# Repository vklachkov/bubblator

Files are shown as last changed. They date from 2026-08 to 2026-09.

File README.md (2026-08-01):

# Bubblator

> [!WARNING]
> This project is unfinished. Nothing is known to work yet. Do not use this board with real bubble-memory modules. It may damage rare hardware. Please wait for tested hardware, firmware, and clear operating instructions.

Bubblator is an experimental board for reading, writing, and attempting to restore Intel 7110 bubble-memory modules.

It follows the Intel Bubble Memory System design and uses the following main parts:

- Intel 7110 / 7110A(Z) One Megabit Bubble Memory Unit
- Intel 7220-1 Bubble Memory Controller
- Intel 7230 Current Pulse Generator
- Intel 7242 Formatter/Sense Amplifier
- Intel 7250 Coil Predriver
- 2x Intel 7254 driver transistors
- Arduino Nano

Firmware serial commands are described in [firmware/COMMANDS.md](firmware/COMMANDS.md).

## Documentation Used

The following Intel documents were used during development:

- [Megabits to Megabytes: Bubble Memory System Design and Board Layout (AP-187, 1984)](https://archive.org/details/bitsavers_intelbubbl87MegabitsToMegabytesBubbleMemorySystemD_3867950) - system design, board layout, and implementation guidance.
- [Intel Bubble Memory Design Handbook](https://archive.org/details/IntelBubbleMemoryDesignHandbook) - bubble-memory principles and design reference.
- [Intel BPK72 Bubble Storage Prototype Kit](https://web.archive.org/web/20190419090939/https://www.wolfgangrobel.de/museum/files_bubble5/intel%20BPK72%20Prototype%20kit%20users%20manual.pdf) - reference prototype system and kit documentation.
- [Intel 7220 Controller for 1Mbit BPK 70A Bubble Memory Subsystem](https://web.archive.org/web/20250912182130/https://wolfgangrobel.de/museum/files_bubble5/intel%207220%20bubble%20memory%20controller.pdf) - datasheet for the Intel 7220 bubble-memory controller.

Further project background:
- [ArduBubble / ReBubbling on the Unix Haters Wiki](https://wiki.unix-haters.org/doku.php?id=grid:rebubbling)

## Authors

- **sabur** - original firmware code.
- **grm** - initial hardware design.
- **BOOtak** - created the second PCB revision and assembled the prototype.
- **vklachkov** - continued the work of others.

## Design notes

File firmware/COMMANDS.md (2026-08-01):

# Firmware Serial Commands

> [!WARNING]
> The firmware and hardware are unfinished. Do not use write, reset, purge, or other commands with a real bubble-memory module. They may change data or damage rare hardware.

> [!NOTE]
> An LLM created this document by reading `firmware.ino`. Treat it with great caution. It has not been verified.

The firmware uses the Arduino Nano USB serial port at **115200 baud**. Send one command per line. Both `LF` and `CR` line endings are accepted. Command letters are case-insensitive.

The command line is limited to 63 characters. A longer line is discarded.

## Basic Commands

| Command | Description |
| --- | --- |
| `i0` | Release reset and load normal parameters: two formatter/sense amplifier (FSA) channels and one page per transfer. |
| `i1` | Release reset and load diagnostic parameters: one FSA channel and one page per transfer. |
| `i2` | Release reset and load Write Bootloop parameters. This enables writing to the bootloop. |
| `r` | Assert controller reset when it is not busy. Run `i0`, `i1`, or `i2` afterwards to release reset. |
| `rf` | Force reset even when the controller reports busy. This may cause data loss. Run an `i` command afterwards to release reset. |
| `s` | Read and print the controller status register. |
| `fr` | Read the controller FIFO and print its contents. |
| `fw <hex bytes>` | Write hexadecimal bytes to the controller FIFO. At most 43 bytes are written. |

For `fw`, values may be separated by spaces, commas, or colons. The `0x` prefix is optional. Each value may have one or two hexadecimal digits; one digit is stored as `0x0N`. For example:

```text
fw FF 00 A5 7E
fw 0xFF,0x00,0xA5,0x7E
```

## Controller Commands

Use `c` followed by a command code. For example, `c1` sends the controller Initialize command. These commands directly access the Intel 7220 controller.

| Command | Intel 7220 operation | Notes |
| --- | --- | --- |
| `c0` | Write Bootloop Register Masked | Direct controller command. |
| `c1` | Initialize | Direct controller command. |
| `c2` | Read Bubble Data | Direct controller command. |
| `c3` | Write Bubble Data | Direct controller command. |
| `c4` | Read Seek | Direct controller command. |
| `c5` | Read Bootloop Register | Direct controller command. |
| `c6` | Write Bootloop Register | Not implemented: the firmware does not send this command. |
| `c7` | Write Bootloop | Not implemented: the firmware does not send this command. |
| `c8` | Read FSA Status | Direct controller command. |
| `c9` | Abort | Abort the current operation. After it completes, run Initialize or MBM Purge; MBM Purge may be destructive. |
| `ca` | Write Seek | Direct controller command. |
| `cb` | Read Bootloop | Direct controller command. |
| `cc` | Read Corrected Data | Direct controller command. |
| `cd` | Reset FIFO | Direct controller command. |
| `ce` | MBM Purge | Direct controller command. This is potentially destructive. |
| `cf` | Software Reset | Direct controller command. |
| `cx` | Fill FIFO with 34 ones | Not implemented. |
| `cz` | Fill FIFO with 40 ones | Not implemented. |

After each `c` command, the firmware polls for completion or failure for up to about two seconds. It prints `Operation Timed Out!` if neither status appears. This wait also runs for the unimplemented commands. Some direct commands require correctly configured registers and FIFO contents; the firmware does not validate that setup.

## Page Read and Write

Page commands are sent as controller commands with `r` or `w` as the code:

```text
cr <first page> [last page]
cw <first page> [last page]
```

Examples:

```text
cr 0
cr 10 15
cw 42
```

Pages are decimal numbers from `0` to `2047`. A comma or colon may also separate the two page numbers. An omitted or invalid first page defaults to `0`. An omitted or invalid last page defaults to the selected first page.

- `cr` reads one page or an inclusive page range. Each page contains 68 bytes: 64 data bytes and 4 error-correction bytes. The result is printed in hexadecimal and printable ASCII.
- `cw` writes one page or an inclusive page range. **The current firmware always writes `FF` to all 68 bytes of every selected page.** It makes at most five write attempts per page. The current code may print `Abort...` after the fifth attempt even when that final attempt succeeds.

Both commands can wait forever for `FIFOReady` if the controller is unavailable or incorrectly configured. There is no timeout for this wait.

Do not run `cw` on a real module.

## Status Output

The `s` command can print these flags:

- `Busy` - controller operation is in progress.
- `OpComplete` - the operation completed.
- `OpFail` - the operation failed.
- `TimingError`, `CorrectableError`, `UncorrectableError`, and `ParityError` - controller error conditions.
- `FIFOReady` - data is available in the FIFO.

## Unavailable Commands

The parser also accepts `a` and `u`, but their handlers are disabled in the current firmware. They require one parameter character (for example, `ax` or `ux`) and then have no effect. `a` or `u` alone reports a missing parameter.

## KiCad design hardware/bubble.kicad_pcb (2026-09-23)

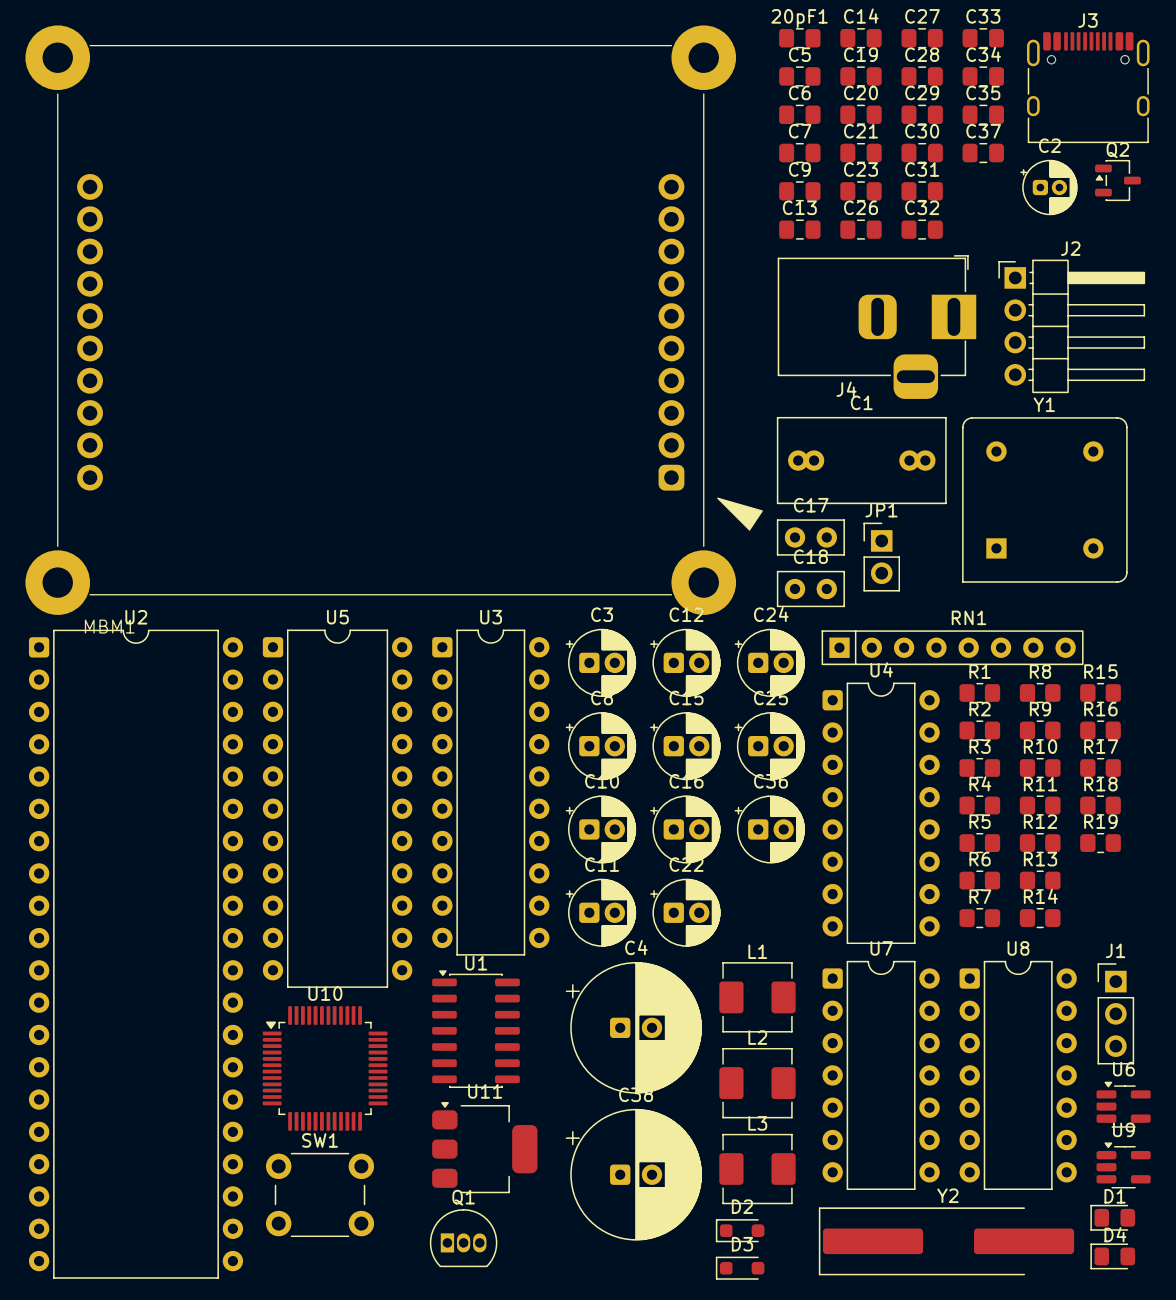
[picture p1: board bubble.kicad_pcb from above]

Board: 4 copper layers, 88 parts (0 on the bottom side), 103 nets, no tracks yet.

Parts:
20pF1: C; C_0805_2012Metric_Pad1.18x1.45mm_HandSolder
C1: 0.33 uF; C_Rect_L13.0mm_W6.5mm_P7.50mm_P10.00mm
C2: 22uF; CP_Radial_D4.0mm_P1.50mm
C3, C8, C10, C11, C36: 47uF; CP_Radial_D5.0mm_P2.00mm
C4, C38: 150uF; CP_Radial_D10.0mm_P2.50mm
C5, C6, C7, C9, C13, C14, C19, C20, C21, C31, C32, C33, C35, C37: 0.1uF; C_0805_2012Metric_Pad1.18x1.45mm_HandSolder
C12, C15, C22, C24, C25: 22uF; CP_Radial_D5.0mm_P2.00mm
C16: 22uF 25V; CP_Radial_D5.0mm_P2.00mm
C17, C18: 120 pF 100V 5%; C_Disc_D5.0mm_W2.5mm_P2.50mm
C23: 2.2 uF; C_0805_2012Metric_Pad1.18x1.45mm_HandSolder
C26, C27: 0.01 uF; C_0805_2012Metric_Pad1.18x1.45mm_HandSolder
C28: 10 uF; C_0805_2012Metric_Pad1.18x1.45mm_HandSolder
C29: 20pF; C_0805_2012Metric_Pad1.18x1.45mm_HandSolder
C30, C34: 22uF; C_0805_2012Metric_Pad1.18x1.45mm_HandSolder
D1: POWER FAILED LED; LED_0805_2012Metric_Pad1.15x1.40mm_HandSolder
D2, D3: D; D_SOD-323_HandSoldering
D4: LED; LED_0805_2012Metric_Pad1.15x1.40mm_HandSolder
J1: Conn_01x03_Pin; PinHeader_1x03_P2.54mm_Vertical
J2: Conn_01x04_Pin; PinHeader_1x04_P2.54mm_Horizontal
J3: USB-C; USB_C_Receptacle_HRO_TYPE-C-31-M-12
J4: 12V Power; BarrelJack_Horizontal
JP1: Only for reseed; PinHeader_1x02_P2.54mm_Vertical
L1, L2, L3: 0.22 uH; L_APV_APH0530
MBM1: i7110; MBM_socket
Q1: BS170; TO-92_Inline
Q2: DTC113Z; SOT-23-3
R1, R2, R13, R15, R16: 5.1k; R_0805_2012Metric_Pad1.20x1.40mm_HandSolder
R3: 3.48k; R_0805_2012Metric_Pad1.20x1.40mm_HandSolder
R4: 10; R_0805_2012Metric_Pad1.20x1.40mm_HandSolder
R5: 300; R_0805_2012Metric_Pad1.20x1.40mm_HandSolder
R6: 47; R_0805_2012Metric_Pad1.20x1.40mm_HandSolder
R7: 1k; R_0805_2012Metric_Pad1.20x1.40mm_HandSolder
R8: 3.9k; R_0805_2012Metric_Pad1.20x1.40mm_HandSolder
R9: 5.5k; R_0805_2012Metric_Pad1.20x1.40mm_HandSolder
R10: 33k; R_0805_2012Metric_Pad1.20x1.40mm_HandSolder
R11, R12: 5.1; R_0805_2012Metric_Pad1.20x1.40mm_HandSolder
R14: 300Ohm; R_0805_2012Metric_Pad1.20x1.40mm_HandSolder
R17, R18: 22; R_0805_2012Metric_Pad1.20x1.40mm_HandSolder
R19: 1.5k; R_0805_2012Metric_Pad1.20x1.40mm_HandSolder
RN1: 1k; R_Array_SIP8
SW1: Reset; SW_PUSH_6mm_H5mm
U1: 74LS74; SOIC-14_3.9x8.7mm_P1.27mm
U2: i7220; DIP-40_W15.24mm
U3: i7242; DIP-20_W7.62mm
U4: i7250; DIP-16_W7.62mm
U5: i7230; DIP-22_W10.16mm
U6: 74AHC1G00; SOT-23-5_HandSoldering
U7, U8: i7254; DIP-14_W7.62mm
U9: 74LVC1G07; SOT-23-5_HandSoldering
U10: STM32F103C8Tx; LQFP-48_7x7mm_P0.5mm
U11: AMS1117-3.3; SOT-223-3_TabPin2
Y1: 8.000 MHz; Oscillator_DIP-8
Y2: 8Mhz; Crystal_SMD_HC49-SD_HandSoldering

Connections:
+3.3V: C33.1, C34.1, J1.3, J2.4, R19.2, U10.9 (VDDA), U10.24 (VDD), U10.36 (VDD), U10.48 (VDD), U11.2 (VO)
+5V: C5.1, C8.1, C11.1, C13.1, C30.1, C32.1, C35.2, C36.2, D1.2 (A), J3.A4 (VBUS), J3.A9 (VBUS), J3.B4 (VBUS), J3.B9 (VBUS), L1.2, R1.1, R2.1, R7.1, R13.2, U1.1 (~R), U1.4 (~S), U1.14 (VCC), U2.40 (VCC), U3.20 (VCC), U6.5 (VCC), U9.5 (VCC), U11.3 (VI), Y1.1 (EN), Y1.8 (Vcc)
+12V: C9.1, C10.1, C12.1, C20.1, C21.1, C24.1, C25.1, C37.1, C38.1, J4.1, JP1.2 (B), L2.2, R4.2, R6.2, R11.2, U4.16 (VDD), U7.6 (S2), U7.13 (S4), U8.6 (S2), U8.13 (S4)
/MBM/7230 VCC: C4.1, C7.1, L3.1, U5.22 (VCC)
/MBM/7230 VDD: C2.1, C3.1, C6.1, L2.1, U5.1 (VDD)
/MBM/~7220 POWER.FAIL: C23.1, C26.1, D3.2 (A), Q2.3 (C), R8.2, U2.1 (~PWR.FAIL)
/MBM/~7220 RESET.OUT: R13.1, U2.2 (~RESET.OUT), U6.2, U9.2
A0: U2.10 (A0), U10.42 (PB6)
BOOT: J1.2, U10.44 (BOOT0)
CLK: U1.5 (Q), U2.3 (CLK), U3.18 (CLK), U10.3 (PC14)
D0: U2.11 (D0), U10.43 (PB7)
D1: U2.12 (D1), U10.45 (PB8)
D2: U2.13 (D2), U10.46 (PB9)
D3: U2.14 (D3), U10.21 (PB10)
D4: U2.15 (D4), U10.22 (PB11)
D5: U2.16 (D5), U10.25 (PB12)
D6: U2.17 (D6), U10.26 (PB13)
D7: U2.18 (D7), U10.27 (PB14)
D8: U2.19 (D8), U10.28 (PB15)
DRQ: U2.8 (DRQ), U10.29 (PA8)
GND: 20pF1.1, C1.2, C2.2, C3.2, C4.2, C5.2, C6.2, C7.2, C8.2, C9.2, C10.2, C11.2, C12.2, C13.2, C14.2, C15.2, C20.2, C21.2, C23.2, C24.2, C25.2, C26.2, C27.2, C28.2, C29.1, C30.2, C31.1, C32.2, C33.2, C34.2, C35.1, C36.1, C37.2, C38.2, J1.1, J2.1, J3.A1 (GND), J3.A12 (GND), J3.B1 (GND), J3.B12 (GND), J3.SH (SHIELD), J4.2, Q1.3 (S), Q2.2 (E), R10.2, R12.1, R14.1, R15.2, R16.1, SW1.2, U1.7 (GND), U2.20 (GND), U3.1 (~CS), U3.10 (GND), U4.8 (GND), U5.11 (GND), U5.12 (GND), U6.3 (GND), U7.2 (S1), U7.9 (S3), U8.2 (S1), U8.9 (S3), U9.3 (GND), U10.8 (VSSA), U10.23 (VSS), U10.35 (VSS), U10.47 (VSS), U11.1 (GND), Y1.4 (GND)
INT: U2.9 (INT), U10.39 (PB3)
NRST: C31.2, SW1.1, U10.7 (NRST)
unnamed: C1.1, L1.1, L3.2
unnamed: C16.2, MBM1.1 (PULSE.COM(+12V)), MBM1.6 (PULSE.COM(+12V))
unnamed: D1.1 (K), R5.2
unnamed: D2.1 (K), R8.1
unnamed: D3.1 (K), R9.1
unnamed: D4.1 (K), R14.2
unnamed: J3.A5 (CC1), R15.1
unnamed: J3.B5 (CC2), R16.2
unnamed: J3.A6 (D+), J3.B6 (D+), R18.1, R19.1
unnamed: J3.A7 (D-), J3.B7 (D-), R17.1
unnamed: C16.1, JP1.1 (A), R6.1
unnamed: MBM1.4 (BOOT.REP), U5.13 (BOOT.REP)
unnamed: MBM1.5 (BOOT.SWAP), U5.14 (BOOT.SWAP)
unnamed: C19.2, C22.2, MBM1.15 (DET.COM), R12.2
unnamed: MBM1.19 (DET.OUT.A+), RN1.5 (R4.2)
unnamed: MBM1.18 (DET.OUT.A-), RN1.6 (R3.2)
unnamed: MBM1.17 (DET.OUT.B+), RN1.7 (R2.2)
unnamed: MBM1.16 (DET.OUT.B-), RN1.8 (R1.2)
unnamed: C19.1, C22.1, MBM1.20 (DET.SUPPLY), R11.1
unnamed: MBM1.7 (GEN.A), U5.18 (GEN.A)
unnamed: MBM1.8 (GEN.B), U5.19 (GEN.B)
unnamed: MBM1.3 (REP.A), U5.15 (REP.A)
unnamed: MBM1.2 (REP.B), U5.16 (REP.B)
unnamed: MBM1.13 (SWAP.A), MBM1.14 (SWAP.B), U5.17 (SWAP)
unnamed: MBM1.10 (X+.COIL.IN), U7.7 (D2), U7.8 (D3)
unnamed: MBM1.9 (X-.COIL.IN), U7.1 (D1), U7.14 (D4)
unnamed: MBM1.12 (Y+.COIL.IN), U8.1 (D1), U8.14 (D4)
unnamed: MBM1.11 (Y-.COIL.IN), U8.7 (D2), U8.8 (D3)
unnamed: Q1.1 (D), R3.1
unnamed: Q2.1 (B), U6.4
unnamed: C18.2, RN1.1 (R1.1), U3.9 (DET.B-)
unnamed: C18.1, RN1.2 (R2.1), U3.8 (DET.B+)
unnamed: C17.2, RN1.3 (R3.1), U3.7 (DET.A-)
unnamed: C17.1, RN1.4 (R4.1), U3.6 (DET.A+)
unnamed: U1.3 (C), Y1.5 (OUT)
unnamed: U1.2 (D), U1.6 (~Q)
unnamed: U2.29 (C/~D), U3.3 (C/~D)
unnamed: U2.22 (DIO), U3.17 (DIO)
unnamed: U2.32 (~BOOT.EN), U5.10 (~BOOT.EN)
unnamed: U2.30 (~BOOT.SW.EN), U5.9 (~BOOT.SW.EN)
unnamed: U2.33 (~REP.EN), U5.8 (~REP.EN)
unnamed: U2.24 (~SHIFT.CLK), U3.15 (~SHIFT.CLK)
unnamed: U2.31 (~SWAP.EN), U5.6 (~SWAP.EN)
unnamed: U2.23 (~SYNC), U3.19 (~SELECT.IN)
unnamed: U2.35 (~TM.A), U5.2 (~TM.A)
unnamed: U2.34 (~TM.B), U5.3 (~TM.B)
unnamed: U2.39 (~X+), U4.3 (~X+.IN)
unnamed: U2.38 (~X-), U4.4 (~X-.IN)
unnamed: U2.37 (~Y+), U4.5 (~Y+.IN)
unnamed: U2.36 (~Y-), U4.6 (~Y-.IN)
unnamed: C14.1, C15.1, R4.1, U3.5 (VDD)
unnamed: U3.11 (~DATA.OUT.A), U5.5 (~GEN.EN.A)
unnamed: U3.12 (~DATA.OUT.B), U5.4 (~GEN.EN.B)
unnamed: U3.13 (~ENABLE.A), U4.1 (~CS), U5.7 (~CS)
unnamed: U4.14 (X+.OUT), U7.3 (G1)
unnamed: U4.12 (X-.OUT), U7.10 (G3)
unnamed: U4.10 (Y+.OUT), U8.10 (G3)
unnamed: U4.7 (Y-.OUT), U8.3 (G1)
unnamed: U4.15 (~X+.OUT), U7.5 (G2)
unnamed: U4.13 (~X-.OUT), U7.12 (G4)
unnamed: U4.11 (~Y+.OUT), U8.12 (G4)
unnamed: U4.9 (~Y-.OUT), U8.5 (G2)
unnamed: R3.2, U5.20 (REFR)
unnamed: C29.2, U10.5 (PD0), Y2.2
unnamed: 20pF1.2, U10.6 (PD1), Y2.1
STATUS_LED: D4.2 (A), U10.2 (PC13)
SWCLK: J2.2, U10.37 (PA14)
SWDIO: J2.3, U10.34 (PA13)
USB_D+: R18.2, U10.33 (PA12)
USB_D-: R17.2, U10.32 (PA11)
~BUS.RD: U2.25 (~BUS.RD), U10.31 (PA10)
~CS: U2.21 (~CS), U10.4 (PC15)
~DACK: U2.7 (~DACK), U10.30 (PA9)
~DET.ON: U2.28 (~DET.ON), U10.40 (PB4)
~ERR_FLAG: R1.2, U2.27 (~ERR.FLG), U3.4 (~ERR.FLG), U10.41 (PB5)
~POWER.FAIL: C27.1, D2.2 (A), R5.1, R7.2, U2.4 (~RESET), U5.21 (~PWR.FAIL), U6.1
~RD: U2.5 (~RD), U10.18 (PB0)
~RESET.BUS: C28.1, Q1.2 (G), R9.2, R10.1, U3.16 (~RESET), U4.2 (~RESET), U9.4, U10.38 (PA15)
~WAIT: R2.2, U2.26 (~WAIT), U10.20 (PB2)
~WR: U2.6 (~WR), U10.19 (PB1)

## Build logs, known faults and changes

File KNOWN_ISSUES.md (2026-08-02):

Known board issues identified during debugging with a physical module.

> [!NOTE]
> These issues are not fixed in the project. This document is a collection of debugging notes and required manual modifications.

## Required Patches

- Connect 7220 pin 21 (`~CS`) to GND.
- Connect 7220 pin 7 (`~DACK`) to +5 V through a 5.1 kOhm resistor.
- Connect 7110 pin 6 to 7110 pin 1. Pin 6 is marked as NC, but reference schematics connect it to pin 1. The Bubble Memory Design Handbook identifies it as `PULSE.COM` (+12 V) and also requires this connection.
- Swap 7250 pins 14 and 12.
- Move R2 from the transistor source to its drain, placing it in series between 7230 pin 20 and transistor pin 3.

## Design Issues

- The board is highly sensitive to power-supply quality and operates reliably only with a stable bench power supply.
- The `DET.A` and `DET.B` differential pair between 7110 and 7242 lacks shielding and trace-length control.
- `PULSE.COM` (+12 V) is routed through 2 W resistors.
- The socket footprint for 7230 is unsuitable.
- R4 lacks a bypass jumper for reseeding.
- Small SMD components around the module prevent installation of a suitable socket.
- Arcing occurs during power-up when C25 is populated.

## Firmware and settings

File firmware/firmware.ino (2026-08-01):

// Define Bi-Directional Data Bus (Without Pin 9, which is used for Clock)
#define ad0 11
#define ad1 10
#define ad2 8
#define ad3 7
#define ad4 6
#define ad5 5
#define ad6 4
#define ad7 3
#define adp 2 // Odd Parity

#define ClockOut 9 // Clock Output Pin
#define OcrInt 1   // 4 Mhz Clock Pulse

// Control Pins (Using Analog In)
#define rs A0 // Reset: Low Enables Reset
#define cd 12 // A0: High Selects Command/Status, Low Selects Data Register
#define rd A1 // Read: Low Enables BMC Output to Data Bus
#define wr A2 // Write: Low Enables Data Bus Input to BMC

// Base definitions for Command Register, Register Address Counter, and Status Register access (A0 = 1)
#define cmdr 0b00010000 // 0b0001CCCC

// Command Codes
#define wBootloopRegMasked  0b0000
#define initialize          0b0001
#define rBubbleData         0b0010
#define wBubbleData         0b0011
#define rSeek               0b0100
#define rBootloopReg        0b0101
#define wBootloopReg        0b0110
#define wBootloop           0b0111
#define rFsaStatus          0b1000
#define abortCmd            0b1001
#define wSeek               0b1010
#define rBootloop           0b1011
#define rCorrectedData      0b1100
#define resetFifo           0b1101
#define mbmPurge            0b1110
#define softwareReset       0b1111

// User-Accessible Registers (A0 = 0)
#define rwUtility        0b1010
#define wBlockLengthLsb  0b1011
#define wBlockLengthMsb  0b1100
#define wEnable          0b1101
#define rwAddressLsb     0b1110
#define rwAddressMsb     0b1111
#define rwFifoDataBuffer 0b0000

// User-Accessible Register Masks
#define nMbmSelectArMsb    0b01111000 // MBM Select from rwAddressMsb XAAAASSS
#define nStartAddressArMsb 0b00000111 // Start Address within each MBM from rwAddressMsb XAAAASSS

// Status Register Masks
#define fifoReady           0b00000001
#define parityError         0b00000010
#define uncorrectableError  0b00000100
#define correctableError    0b00001000
#define timingError         0b00010000
#define opFail              0b00100000
#define opComplete          0b01000000
#define busy                0b10000000

// FSA Status Register Masks
#define fsaUncorrectableError 0b00000001
#define fsaCorrectableError   0b00000010
#define fsaTimingError        0b00000100
#define errorCorrectionEnable 0b00001000
#define fifoFull              0b00010000
#define fifoEmpty             0b00100000
#define SpareTwo              0b01000000
#define SpareOne              0b10000000

// Enable Register Masks
#define interruptEnable       0b00000001
#define interruptEnableError  0b00000010
#define dmaEnable             0b00000100
#define maxFsaBmcTransferRate 0b00001000
#define writeBootloopEnable   0b00010000
#define enableRcd             0b00100000 // Read Corrected Data
#define enableIcd             0b01000000 // Internally Correct Data
#define enableParityInterrupt 0b10000000

// Buffer for reading and writing to the FIFO using single page requests
// Also used for FIFO operations
// 2 FSA Channels, 1 MBM
// 2048 Pages, 0x0000-0x07FF
// 64 Bytes + 4 Bytes Error Correction
byte rwBuffer[68];
bool rwParityBuffer[68];

// Serial command input for Arduino Nano. A command is executed only after
// CR or LF is received. Fixed-size storage avoids String heap fragmentation.
const byte commandLineCapacity = 64;
char commandLine[commandLineCapacity];
byte commandLineLength = 0;
bool commandLineOverflow = false;
char* commandArguments = NULL;

/* Good Seeds
  byte seed_6ADH3_8133[40] = {
  0xFF, 0xFE, 0xFF, 0xFE, 0xFD, 0x7D, 0xCE, 0xFF,
  0xFF, 0xFF, 0xEE, 0xFF, 0xCF, 0xBF, 0xFF, 0xFF,
  0xFF, 0xBF, 0xFD, 0xF3, 0xFF, 0xFF, 0xFF, 0xFF,
  0xEF, 0x6F, 0xFA, 0xEE, 0xFF, 0x6E, 0xE6, 0xFE,
  0x7F, 0xFF, 0xFF, 0xFE, 0xFF, 0xFF, 0xFF, 0xDF
  };

// 4EC3 8021
// 77 77 57 77 77 77 77 77 wwWwwwww
// F7 FF FF FB FF FF FF FF ........
// FF FF FF BF FF FF FF FF ........
// FF FF FF FF F9 FF FF DD ........
// FF FF FF FF FF FF FF FF ........

  byte seed_4EC3_8021[40] = {
  0x77, 0x77, 0x57, 0x77, 0x77, 0x77, 0x77, 0x77,
  0xF7, 0xFF, 0xFF, 0xFB, 0xFF, 0xFF, 0xFF, 0xFF,
  0xFF, 0xFF, 0xFF, 0xBF, 0xFF, 0xFF, 0xFF, 0xFF,
  0xFF, 0xFF, 0xFF, 0xFF, 0xF9, 0xFF, 0xFF, 0xDD,
  0xFF, 0xFF, 0xFF, 0xFF, 0xFF, 0xFF, 0xFF, 0xFF
  };

  byte seed_A94R_8152[40] = {
  0xFF, 0xFF, 0xFB, 0xFF, 0xFF, 0xFF, 0xFF, 0xF5,
  0xFF, 0xFF, 0xBA, 0xFF, 0xFF, 0xCF, 0x7F, 0xFF,
  0xDF, 0x7D, 0xFF, 0xF4, 0xFF, 0xFF, 0xEF, 0xEF,
  0xF9, 0xDF, 0xFF, 0xFF, 0xEF, 0xFE, 0xFF, 0xFF,
  0xFF, 0xFF, 0xF7, 0x7F, 0xFF, 0xDF, 0xFF, 0xFF
  };

  byte seed_B84S_8214[40] = {
  0xFF, 0xFF, 0xFB, 0xFD, 0xFF, 0xFF, 0xFF, 0xF7,
  0xFF, 0xFF, 0xFF, 0xFF, 0xFF, 0xFB, 0xFF, 0xEF,
  0xBF, 0xFF, 0xF5, 0xFF, 0xFF, 0xFF, 0xFF, 0xFF,
  0xFF, 0xFF, 0xFF, 0xFF, 0x7F, 0xEE, 0xFF, 0xFF,
  0xBE, 0xFE, 0xFF, 0xFF, 0xFF, 0xFF, 0xFF, 0xDF
  };

  byte seed_9ADJ5_8135[40] = {
  0x77, 0x7F, 0xFF, 0x7D, 0xFF, 0xFF, 0xFF, 0xFF,
  0xFF, 0xEE, 0x7F, 0xF7, 0xFF, 0xBF, 0xFF, 0xFF,
  0xFF, 0xFF, 0xFF, 0xFF, 0xFF, 0xFF, 0xFF, 0xFF,
  0xFF, 0xFB, 0xFF, 0xFF, 0xEF, 0xFF, 0xFF, 0xFF,
  0xFF, 0xFF, 0xFF, 0xFF, 0xFF, 0xFF, 0xFF, 0xEF
  };

  byte seed_1MZ8_8129[40] = {
  0xEB, 0xEE, 0xB5, 0xDF, 0xFF, 0xFF, 0xFD, 0xFF,
  0xFF, 0xFF, 0xFF, 0xFF, 0xFF, 0xDF, 0xFF, 0xFF,
  0xFF, 0xFF, 0xFF, 0xFF, 0x7F, 0xDF, 0xFF, 0xFF,
  0xFF, 0x77, 0xFF, 0xFF, 0xFF, 0xFF, 0xDE, 0xF7,
  0xFF, 0xFF, 0xFF, 0xFF, 0x5F, 0xFF, 0xFF, 0xFF
  };
*/

void setup() {
	Serial.begin(115200); // Arduino Nano USB serial
	Serial.println("Starting...");

	pinMode(rs, OUTPUT);
	pinMode(cd, OUTPUT);
	pinMode(rd, OUTPUT);
	pinMode(wr, OUTPUT);
	pinMode(LED_BUILTIN, OUTPUT);

	// Start 4Mhz Clock
	/* This is the 4Mhz Clock on Pin 7 for the Arduino Due
	  int32_t mask_PWM_pin = digitalPinToBitMask(7);
	  REG_PMC_PCER1 = 1 << 4;                         // activate clock for PWM controller
	  REG_PIOC_PDR |= mask_PWM_pin;                   // activate peripheral functions for pin (disables all PIO functionality)
	  REG_PIOC_ABSR |= mask_PWM_pin;                  // choose peripheral option B
	  REG_PWM_CLK = 0;                                // choose clock rate, 0 -> full MCLK as reference 84MHz
	  REG_PWM_CMR6 = 0 << 9;                          // select clock and polarity for PWM channel (pin7) -> (CPOL = 0)
	  REG_PWM_CPRD6 = 21;                             // initialize PWM period -> T = value/84MHz (value: up to 16bit), value=10 -> 8.4MHz
	  REG_PWM_CDTY6 = 5;                              // initialize duty cycle, REG_PWM_CPRD6 / value = duty cycle, for 10/5 = 50%
	  REG_PWM_ENA = 1 << 6;                           // enable PWM on PWM channel (pin 7 = PWML6) */

	  /* This is the 4Mhz Clock on Pin 9 for the Arduino Duemilanove */
	pinMode(ClockOut, OUTPUT);
	TCCR1A = bit(COM1A0);
	TCCR1B = bit(WGM12) | bit(CS10);
	OCR1A = OcrInt;

	// Run Bus Initialization
	softReset(true, 0);

	delay(200);

	Serial.println("Ready.");
}

void loop() {
	while (Serial.available() > 0) {
		char incoming = (char)Serial.read();

		if (incoming == '\n' || incoming == '\r') {
			if (commandLineOverflow) {
				Serial.println("Command too long, line discarded.");
				commandLineOverflow = false;
				commandLineLength = 0;
				Serial.println("Ready.");
				continue;
			}

			if (commandLineLength == 0) {
				continue;
			}

			commandLine[commandLineLength] = '\0';
			processCommandLine(commandLine);
			commandLineLength = 0;
			Serial.println("Ready.");
			continue;
		}

		if (commandLineOverflow) {
			continue; // Discard characters until the line terminator.
		}

		if (commandLineLength < commandLineCapacity - 1) {
			commandLine[commandLineLength++] = incoming;
		}
		else {
			commandLineOverflow = true;
		}
	}
}

void processCommandLine(char* line) {
	char* cursor = line;

	while (*cursor == ' ' || *cursor == '\t') {
		cursor++;
	}

	if (*cursor == '\0') {
		return;
	}

	byte command = (byte)*cursor++;
	if (command >= 'A' && command <= 'Z') {
		command = command - 'A' + 'a';
	}

	while (*cursor == ' ' || *cursor == '\t') {
		cursor++;
	}

	byte parameter = 0;
	if (command != 's' && command != 'r') {
		if (*cursor == '\0') {
			Serial.println("Missing command parameter.");
			return;
		}

		parameter = (byte)*cursor++;
		if (parameter >= 'A' && parameter <= 'Z') {
			parameter = parameter - 'A' + 'a';
		}
	}
	else if (command == 'r' && *cursor != '\0') {
		// Reset accepts optional 'f': rf forces reset while BMC is busy.
		parameter = (byte)*cursor++;
		if (parameter >= 'A' && parameter <= 'Z') {
			parameter = parameter - 'A' + 'a';
		}
	}

	while (*cursor == ' ' || *cursor == '\t') {
		cursor++;
	}
	commandArguments = cursor;

	if (command == 'i') {
		if (parameter < '0' || parameter > '2') {
			Serial.println("Invalid init mode. Use i0, i1 or i2.");
		}
		else {
			processInitBmc(parameter);
		}
	}
	else if (command == 'c') {
		processCommand(parameter);
	}
	else if (command == 'r') {
		if (parameter != 0 && parameter != 'f') {
			Serial.println("Invalid reset command. Use r or rf.");
		}
		else {
			Serial.println("Reset...");
			softReset(false, parameter);
		}
	}
	else if (command == 's') {
		rStatusRegister(readbyte(true));
	}
	else if (command == 'f') {
		if (parameter != 'r' && parameter != 'w') {
			Serial.println("Invalid FIFO command. Use fr or fw.");
		}
		else {
			processFifo(parameter);
		}
	}
	else if (command == 'a') {
		// rAllRegisterValues();
	}
	else if (command == 'u') {
		// processUserRegister(parameter);
	}
	else {
		Serial.println("Unknown command.");
	}

	commandArguments = NULL;
}

void processInitBmc(byte initByte) {
	Serial.println("Running.");
	digitalWrite(rs, HIGH);
	digitalWrite(LED_BUILTIN, HIGH);
	delayMicroseconds(200);

	// Initialize BMC
	// Set initial RAC Value
	wRegisterAddressCounter(wBlockLengthLsb, true);

	if (initByte == '0') {
		Serial.println("Loading normal parametric registers...");

		// Write Block Length information
		// N=# of FSA Channels, P=# of Pages Transfered
		// MSB -> NNNNXPPP PPPPPPPP <- LSB
		writebyte(false, 0b00000001); // wBlockLengthLsb (1 Page Transferred)
		writebyte(false, 0b00010000); // wBlockLengthMsb (2 FSA Channels)

		// Set Enable Register
		writebyte(false, 0); // wEnable
	}
	else if (initByte == '1') {
		Serial.println("Loading diagnostic (1 FSA) parametric registers...");

		// Write Block Length information
		// N=# of FSA Channels, P=# of Pages Transfered
		// MSB -> NNNNXPPP PPPPPPPP <- LSB
		writebyte(false, 0b00000001); // wBlockLengthLsb (1 Page Transferred)
		writebyte(false, 0b00000000); // wBlockLengthMsb (1 FSA Channel, Diagnostic)

		// Set Enable Register
		writebyte(false, 0); // wEnable
	}
	else if (initByte == '2') {
		Serial.println("Loading write bootloop parametric registers...");

		// Write Block Length information
		// N=# of FSA Channels, P=# of Pages Transfered
		// MSB -> NNNNXPPP PPPPPPPP <- LSB
		writebyte(false, 0b00000001); // wBlockLengthLsb (1 Page Transferred)
		writebyte(false, 0b00010000); // wBlockLengthMsb (2 FSA Channels)

		// Set Enable Register
		writebyte(false, writeBootloopEnable); // Write Bootloop
	}

	// Write initial MBM Information
	// S=MBM Select, A=Starting Address within each MBM
	// MSB -> XSSSSAAA AAAAAAAA <- LSB
	writebyte(false, 0); // rwAddressLsb
	writebyte(false, 0); // rwAddressMsb 1 MBM in system

	// RAC is now addressed to FIFO
}

void processCommand(byte command) {
	Serial.print("Send command: ");

	// Built-In Commands
	if (command == '0')
	{
		Serial.println("Write Bootloop Register Masked");
		writebyte(true, cmdr | wBootloopRegMasked);
	}
	else if (command == '1')
	{
		Serial.println("Initialize");
		writebyte(true, cmdr | initialize);
	}
	else if (command == '2')
	{
		Serial.println("Read Bubble Data");
		writebyte(true, cmdr | rBubbleData);
	}
	else if (command == '3')
	{
		Serial.println("Write Bubble Data");
		writebyte(true, cmdr | wBubbleData);
	}
	else if (command == '4')
	{
		Serial.println("Read Seek");
		writebyte(true, cmdr | rSeek);
	}
	else if (command == '5')
	{
		Serial.println("Read Bootloop Register");
		writebyte(true, cmdr | rBootloopReg);
	}
	else if (command == '6')
	{
		Serial.println("Write Bootloop Register");
		//fillFifoWithOnes(40);
		//writebyte(true, cmdr | wBootloopReg);
	}
	else if (command == '7')
	{
		Serial.println("Write Bootloop");
		//processWriteBootloop();
	}
	else if (command == '8')
	{
		Serial.println("Read FSA Status");
		writebyte(true, cmdr | rFsaStatus);
		//processFsaStatus();
	}
	else if (command == '9')
	{
		Serial.println("Abort");
		if ((readbyte(true) & busy) != 0) {
			Serial.println("BMC Busy, issue Initialize or MBM Purge after complete.");
		}

		writebyte(true, cmdr | abortCmd);
	}
	else if (command == 'a')
	{
		Serial.println("Write Seek");
		writebyte(true, cmdr | wSeek);
	}
	else if (command == 'b')
	{
		Serial.println("Read Bootloop");
		writebyte(true, cmdr | rBootloop);
	}
	else if (command == 'c')
	{
		Serial.println("Read Corrected Data");
		writebyte(true, cmdr | rCorrectedData);
	}
	else if (command == 'd')
	{
		Serial.println("Reset FIFO");
		writebyte(true, cmdr | resetFifo);
	}
	else if (command == 'e')
	{
		Serial.println("MBM Purge");
		writebyte(true, cmdr | mbmPurge);
	}
	else if (command == 'f')
	{
		Serial.println("Software Reset");
		writebyte(true, cmdr | softwareReset);
	}
	else if (command == 'r')
	{
		Serial.println("Read Bubble Page");
		long page = processPageNumber(0);
		processReadPage(page, processPageNumber(page));
	}
	else if (command == 'w')
	{
		Serial.println("Write Bubble Page");
		long page = processPageNumber(0);
		processWritePage(page, processPageNumber(page));
	}
	else if (command == 'x')
	{
		Serial.println("Fill FIFO with 34 1's");
		//fillFifoWithOnes(34);
	}
	else if (command == 'z')
	{
		Serial.println("Fill FIFO with 40 1's");
		//fillFifoWithOnes(40);
	}

	waitForState(opComplete | opFail, 20, true);
}

long processPageNumber(long startingPage) {
	if (commandArguments == NULL) {
		return startingPage;
	}

	// Skip separators before the next decimal number.
	while (*commandArguments == ' ' || *commandArguments == '\t' ||
	       *commandArguments == ',' || *commandArguments == ':') {
		commandArguments++;
	}

	if (*commandArguments < '0' || *commandArguments > '9') {
		return startingPage;
	}

	long page = 0;
	while (*commandArguments >= '0' && *commandArguments <= '9') {
		page = page * 10 + (*commandArguments - '0');
		commandArguments++;
	}

	if (page >= startingPage && page <= 2047) {
		return page;
	}

	// If invalid, return the supplied default/start page.
	return startingPage;
}

void processReadPage(long startingPage, long endingPage) {
	Serial.print("Read Page ");
	Serial.print(startingPage);

	if (startingPage != endingPage) {
		Serial.print(" - ");
		Serial.println(endingPage);
	}
	else {
		Serial.println();
	}

	for (long page = startingPage; page <= endingPage; page++) {
		Serial.print("Page ");
		Serial.print(page);

		int readAttempt = 5;
		do {
			Serial.print(".");
			readAttempt--;
			readPage(page);
		} while (((waitForState(opComplete | opFail, 20, false) & opFail) > 0) && readAttempt > 0);

		if (readAttempt == 0) {
			Serial.print(" Abort...");
			return;
		}

		Serial.println();
		outputBuffer(rwBuffer, sizeof(rwBuffer), 34);
	}
}

void processWritePage(long startingPage, long endingPage) {
	Serial.print("Write Page ");
	Serial.print(startingPage);

	if (startingPage != endingPage) {
		Serial.print(" - ");
		Serial.println(endingPage);
	}
	else {
		Serial.println();
	}

	// Set buffer to pattern
	// memset(rwBuffer, 0xFF, sizeof(rwBuffer));
	memset(rwParityBuffer, 0, sizeof(rwParityBuffer));
	for (int i = 0; i < sizeof(rwBuffer); i++) {
		byte value = 0xFF;
		rwBuffer[i] = value;
		rwParityBuffer[i] = generateOddParity(value);
	}

	outputBuffer(rwBuffer, sizeof(rwBuffer), 34);

	Serial.print("Writing: ");

	for (long page = startingPage; page <= endingPage; page++) {
		Serial.print(page);

		int readAttempt = 5;
		do {
			readAttempt--;
			Serial.print(".");
			writePage(page);
		} while (((waitForState(opComplete | opFail, 20, false) & opFail) > 0) && readAttempt > 0);

		Serial.print(" ");

		if (readAttempt == 0) {
			Serial.print("Abort...");
			return;
		}
	}

	Serial.println("Done.");
}

void readPage(int pageAddress) {
	// Clear Buffer
	memset(rwBuffer, 0, sizeof(rwBuffer));
	//memset(rwParityBuffer, 0, sizeof(rwParityBuffer));

	// Set address to requested location
	if (!setStartingAddress(pageAddress)) {
		Serial.println("Invalid Address! Must be less than 2048.");
		return;
	}

	// Send Read Command to start reading from FIFO
	writebyte(true, cmdr | rBubbleData);

	// Set address pins to Input
	bus2in();

	// Wait for FIFO to start polling data
	digitalWrite(cd, true);
	while ((quickReadByte() & fifoReady) == 0);

	// Read as quickly as possible
	digitalWrite(cd, false);
	for (int i = 0; i < sizeof(rwBuffer); i++) {
		rwBuffer[i] = quickReadByte();
	}
}

void writePage(int pageAddress) {
	// Set address to requested location
	if (!setStartingAddress(pageAddress)) {
		Serial.println("Invalid Address! Must be less than 2048.");
		return;
	}

	// Reset FIFO
	writebyte(true, cmdr | resetFifo);

	// Send Write Command to start writing from FIFO
	writebyte(true, cmdr | wBubbleData);

	// Set address pins to Input
	bus2in();

	// Wait for FIFO to start polling data
	digitalWrite(cd, true);
	while ((quickReadByte() & fifoReady) == 0);

	// Set address pins to Output
	bus2out();

	// Set A0 to address FIFO
	digitalWrite(cd, false);

	// Process Bytes as fast as possible to keep up with FIFO
	for (int i = 0; i < sizeof(rwBuffer); i++) {
		quickWriteByte(rwBuffer[i], rwParityBuffer[i]);
	}
}

void outputBuffer(byte displayBuffer[], int len, int bytesPerLine) {
	if (len == 0) {
		Serial.println("Buffer Empty.");
		return;
	}

	int lines = len / bytesPerLine;
	int startIndex;
	int endIndex;

	for (int i = 0; i < lines; i++) {
		startIndex = i * bytesPerLine;
		endIndex = startIndex + bytesPerLine;

		outputHexChars(displayBuffer, startIndex, endIndex);
		outputSafeChars(displayBuffer, startIndex, endIndex);

		Serial.println();
	}

	int padding = len % bytesPerLine;

	if (padding == 0) {
		return;
	}

	startIndex = lines * bytesPerLine;
	endIndex = startIndex + padding;

	// Write Trailing HEX
	outputHexChars(displayBuffer, startIndex, endIndex);

	// Padding
	int endPadding = bytesPerLine - padding;
	for (int j = 0; j < endPadding; j++) {
		Serial.print("   ");
	}

	// Write Trailing Chars
	outputSafeChars(displayBuffer, startIndex, endIndex);

	Serial.println();
}

void outputHexChars(byte displayBuffer[], int startIndex, int endIndex) {
	char dataString[3];
	for (int i = startIndex; i < endIndex; i++) {
		sprintf(dataString, "%02X ", displayBuffer[i]);
		Serial.print(dataString);
	}
}

void outputSafeChars(byte displayBuffer[], int startIndex, int endIndex) {
	for (int i = startIndex; i < endIndex; i++) {
		char character = (char)displayBuffer[i];
		// Print safe chars after hex (like a hex editor)
		if ((character >= ' ') && (character <= '~')) {
			// Safe Characters
			Serial.print(character);
		}
		else {
			// Unsafe Characters
			Serial.print(".");
		}
	}
}

/*
  void fillFifoWithOnes(int len) {
  Serial.println("Write all ones to FIFO...");
  for (int i = 0; i < len; i++) {
	if (i % 8 == 0)
	{
	  Serial.println();
	}

	char dataString[2];
	sprintf(dataString, "%02X", 0xFF);
	Serial.print(dataString);

	writebyte(false, 0xFF);
  }
  }

  void processWriteBootloop() {
  fillFifoWithOnes(40);

  Serial.println("Write ones into Bootloop");
  wCommandRegister(wBootloop);
  waitWhileBusy(20);

  Serial.println("Load Seed Data into FIFO...");
  // wFifo(seed_1MZ8_8129, 40);
  writebyte(false, 0); // Append Zero Byte
  } */

byte waitForState(byte waitState, int waitCount, bool displayStatus) {
	byte currentStatus = 0;
	byte previousStatus = 0;
	do {
		waitCount--;
		delay(100);
		currentStatus = readbyte(true);
		if (previousStatus != currentStatus) {
			previousStatus = currentStatus;

			if (displayStatus) {
				rStatusRegister(currentStatus);
			}
		}
	} while ((currentStatus & waitState) == 0 && waitCount > 0);

	if (waitCount == 0)
	{
		Serial.println("Operation Timed Out!");
	}

	return currentStatus;
}

/* Not Needed
  void processFsaStatus() {
  // Read FIFO
  memset(rwBuffer, 0, sizeof(rwBuffer));

  // Only the first two bytes are needed for FSA A/B
  int len = rFifo(2, true);

  for (int i = 0; i < len; i++) {
	byte stats = rwBuffer[i];
	Serial.print("FSA Status:");

	if (stats == 0) {
	  Serial.print(" None");
	}

	if ((stats & fsaUncorrectableError) != 0) {
	  Serial.print(" UncorrectableError");
	}

	if ((stats & fsaCorrectableError) != 0) {
	  Serial.print(" CorrectableError");
	}

	if ((stats & fsaTimingError) != 0) {
	  Serial.print(" TimingError");
	}

	if ((stats & errorCorrectionEnable) != 0) {
	  Serial.print(" ErrorCorrectionEnable");
	}

	if ((stats & fifoFull) != 0) {
	  Serial.print(" FIFOFull");
	}

	if ((stats & fifoEmpty) != 0) {
	  Serial.print(" FIFOEmpty");
	}

	if ((stats & SpareTwo) != 0) {
	  Serial.print(" Spare2");
	}

	if ((stats & SpareOne) != 0) {
	  Serial.print(" Spare1");
	}

	Serial.println();
  }
  }

  void processUserRegister(byte rwByte) {
  if (rwByte == 'r') {
	byte rByte = rAddressedRegister(rwUtility, false);
	Serial.print("User Register Read: ");
	Serial.println(rByte, HEX);
  } else if (rwByte == 'w') {
	int dataByte = Serial.read();
	Serial.print("User Register Write: ");
	Serial.println(dataByte, HEX);
	wRegisterAddressCounter(rwUtility, false);
	writebyte(false, dataByte);
  }
  }
*/
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

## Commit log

2026-09-20 hardware: new board schematic
    [bubble.kicad_pcb, bubble.kicad_sch, mcu.kicad_sch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]
2026-09-22 hardware: add more capacitors, fix critical mistakes in schematic
    [bubble.kicad_sch, mcu.kicad_sch, power.kicad_sch]
2026-09-22 hardware: minor cleanup
    [bubble.kicad_sch]
2026-09-22 hardware: add capacitors near i7254
    [bubble.kicad_sch]
2026-09-22 hardware: connect MBM module like Compass
    [bubble.kicad_sch, mcu.kicad_sch, power.kicad_sch]
2026-09-23 hardware: add powerfail circuit, rework power
    [bubble.kicad_pcb, bubble.kicad_sch, mcu.kicad_sch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]
2026-09-23 hardware: connect input signals from 7220 to stm32 five tolerant pins
    [bubble.kicad_sch, mcu.kicad_sch, power.kicad_sch]
